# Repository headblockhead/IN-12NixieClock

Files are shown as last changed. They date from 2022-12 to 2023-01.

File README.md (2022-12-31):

**WARNING: this README has been translated into English using Google Translate for ease of understanding - it may not make perfect sense**

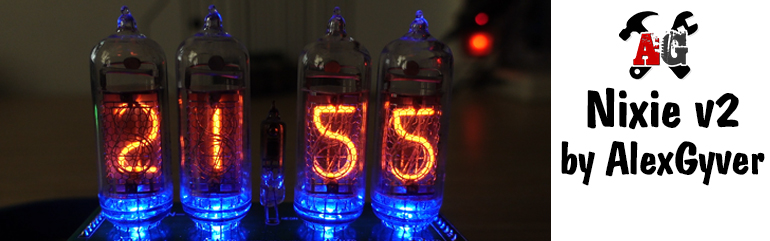
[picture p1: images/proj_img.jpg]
PROJECT_PHOTO

# Clock on gas discharge indicators and Arduino
* [Project Description](#description-of-the-project)
* [Project folders](#folders)
* [Connection diagrams](#scheme)
* [Materials and components](#materials-and-components)
* [How to download and flash](#how-to-download-and-flash)
* [FAQ](#faq)
* [Useful information](#helpful-information)
AlexGyver YouTube (https://www.youtube.com/channel/UCgtAOyEQdAyjvm9ATCi_Aig?sub_confirmation=1)

## Description of the project
Clock on Soviet gas-discharge indicators under the control of the Arduino platform, version 2.
Project page on the website: https://alexgyver.ru/nixieclock_v2/

I decided to make the simplest and most affordable clock project on gas discharge indicators and Arduino! Single-sided board, output components, no tin!

Boards:
- The dimensions of the board are less than 100x100mm, that is, ordering 10 such boards from the Chinese will cost $ 2, excluding delivery
- The board is one-sided, it can be made into a classic LUT without any problems!
- All components are output, even a beginner can solder
- The number of components is reduced to a minimum!
- At the moment, the project has boards for indicators IN-12 and IN-14, perhaps others will be made
- The system consists of two boards: the bottom (all control electronics) and the top (lamps and backlight LEDs)
- There are two options for the lower boards: normal (4 optocouplers, dot - LED) and with an additional optocoupler for a neon dot (5 optocouplers, dot - neon)
- The boards IN-14, IN-12, IN-12_changeling have the same lower part! Parts of the boards are interchangeable. The bottom board is different only for IN-14_neon  

Hardware chips:
- The heart of the board is a full size Arduino NANO, which means easy assembly and firmware
- Power supply of the entire circuit - 5 Volts
- The high voltage generator is driven by the Arduino PWM channel
- The generator voltage is adjusted by a resistor with a twist
- Time sets RTC DS3231
- 3 buttons to set time and alarm
- Alarm buzzer
- Illumination of indicator lamps
- The project is based on Andrey Zheleznyakov's board. Thank you! Link to the project: https://goo.gl/xTVQWP  

Software features:
- “Search” of numbers, preventing the indicators from oxidizing
- Alarm mode
- Smooth change in the brightness of the dot and backlight ("breathing" effect)
	+ Advanced settings for smooth breathing
- Setting the brightness of numbers, “points” and lamp illumination
	+ Two brightness modes depending on the time of day
- Different modes of switching indicators
	+ Smooth fade in/out
	+ Numeric brute force
	+ Enumeration of cathodes

## Folders
**ATTENTION! If this is your first experience with Arduino, read the [manual](#chapter-4)**
- **libraries** - project libraries. Replace existing versions (there are no external libraries in this project)
- **firmware** - firmware for Arduino
- **schemes** - component connection diagrams

## Scheme
Boards:
- IN-14 - for indicators IN-14 with LED dot https://easyeda.com/editor#id=1d7c359f88254c9d9c7ce9de914bd4c5
- IN-14_mini_neon_dot - for IN-14 with dot - indicator (+1 optocoupler and resistor) https://easyeda.com/editor#id=be6c3cd8d42a414b8a8e5b9bdd0401bf
- IN-12 - for IN-12, the numbers are upside down (when looking at the board) https://easyeda.com/editor#id=1d7c359f88254c9d9c7ce9de914bd4c5
- IN-12_turned - for IN-12, numbers are turned correctly https://easyeda.com/editor#id=aea22745380847b5beeca679820e7565  

By opening the board via the link, it can be exported to PDF, PNG or Altium (folder icon on the top left / export) for manufacturing by LUT or other methods!  
When ordering boards from the Chinese, do not forget to indicate in the comment "Please make V-cut along middle thick horizontal outline" to cut the board along the middle line  
**Gerber files are already in the archive!**
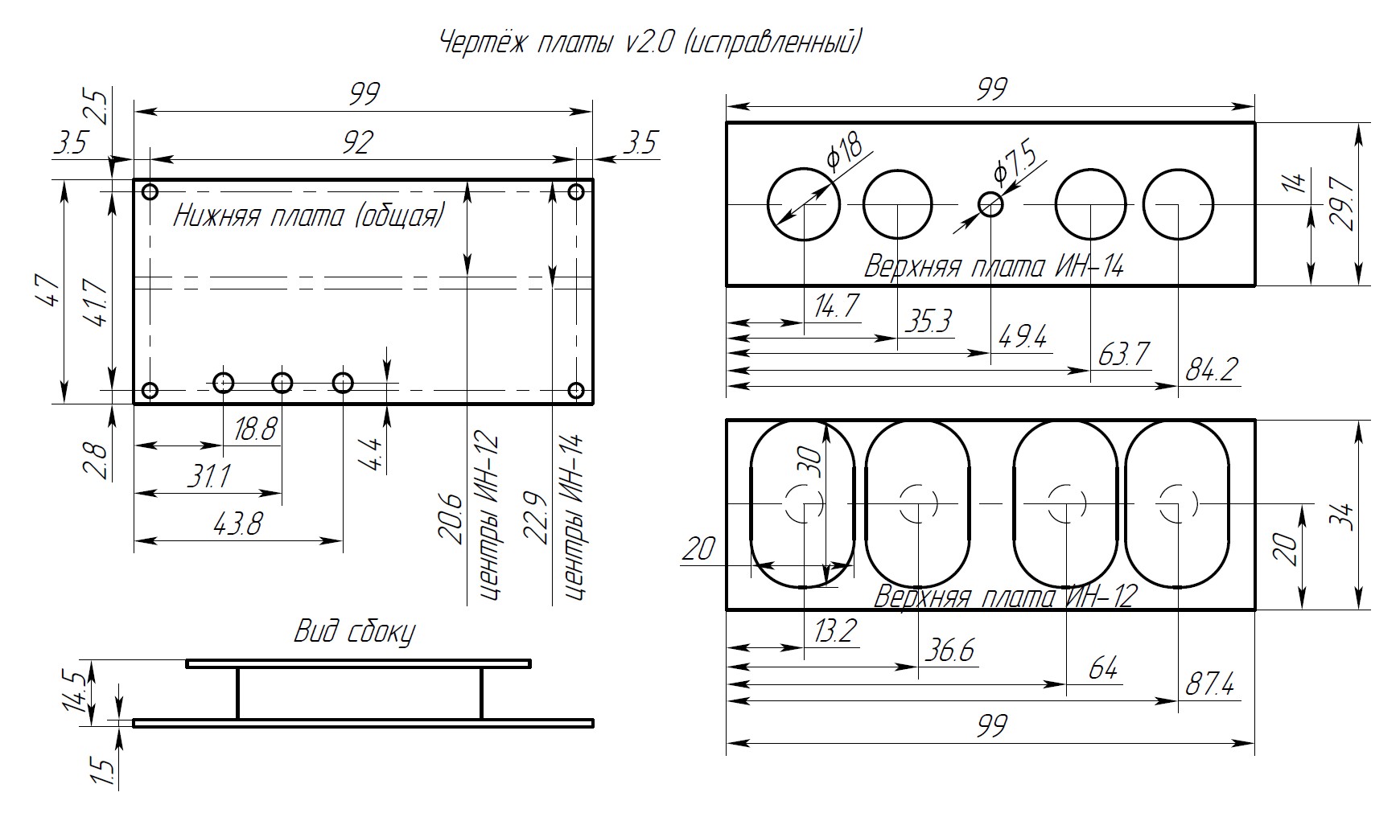
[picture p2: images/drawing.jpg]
SCHEME


## Materials and components
### Links are left to stores from which I have been buying for more than one year
- Arduino NANO Rev3.0 https://ali.ski/670JrC https://ali.ski/_7IUJ
- RTC DS3231 https://ali.ski/gOYYG0
- Squeaker https://ali.ski/8LEYlE
- Sockets for the board https://www.chipdip.ru/product/pbs-40
- Pin rail https://www.chipdip.ru/product/pls-40
- Electrolytic capacitor 4.7 uF 350V https://www.chipdip.ru/product0/33635
- Trimmer resistor 470 kOhm (can be 500 kOhm) https://www.chipdip.ru/product/3362p-1-504
- Inductance 220 uH (uH) https://www.chipdip.ru/product/ec24-221k
- Diode HER106 https://www.chipdip.ru/product/her106
- Transistor IRF840PBF https://www.chipdip.ru/product/irf840
- Optocoupler TLP627(F) DIP-4 https://www.chipdip.ru/product/tlp627
- Decoder K155ID1 https://www.chipdip.ru/product/k155id1
- Resistors 0.25 W for version IN12/IN14 with LED dot
	- 150 Ohm
	- 470 Ohm
	- 10 kOhm	
	- 100 Ohm - 3pcs	
- Resistors 0.25 W for version IN14 with neon dot
	- 200 kOhm
	- 470 Ohm
	- 10 kOhm	
	- 100 Ohm - 3pcs

## You will most likely need
* [All for soldering (soldering irons and gadgets)](http://alexgyver.ru/all-for-soldering/)
* [Inexpensive tools](http://alexgyver.ru/my_instruments/)
* [All existing Arduino modules and sensors](http://alexgyver.ru/arduino_shop/)
* [Electronic components](http://alexgyver.ru/electronics/)
* [Batteries and charging modules](http://alexgyver.ru/18650/)

## How to download and flash
* [First steps with Arduino] (http://alexgyver.ru/arduino-first/) - an ultra detailed article on getting started with Arduino, read it first!
* Download the archive with the project
> On the main page of the project (where you are reading this text) at the top right there is a green button **Clone or download**, click it, there will be **Download ZIP**
* Install libraries in  
`C:\Program Files (x86)\Arduino\libraries\` (Windows x64)  
`C:\Program Files\Arduino\libraries\` (Windows x86)
* **Connect external power supply 5 Volt**
* Connect Arduino to computer
* Run the firmware file (which has the .ino extension)
* Configure IDE (COM port, Arduino model, as in the article above)
* Customize what you need for the project
* Click download
* Enjoy  

## FAQ

### Main questions
Q: How to download from this fucking site?  
A: On the main page of the project (where you are reading this text) there is a green button **Clone or download** at the top right, click it, there will be **Download ZIP**

Q: Some .zip file was downloaded, where is it now?  
A: This is an archive. You can open it using standard Windows tools, but I think everyone has WinRAR installed on their computer, you need to right-click the archive and extract it.

Q: I'm a total newbie! What should I do with Arduino, where can I get all the programs?  
A: Read and watch the video http://alexgyver.ru/arduino-first/

Q: Loading / compilation error crashes!
A: Read here: https://alexgyver.ru/arduino-first/#step-5

Q: How much does it cost?  
A: I don't sell anything.

### Questions about this project

## Helpful information
* [My site](http://alexgyver.ru/)
* [Main YouTube channel](https://www.youtube.com/channel/UCgtAOyEQdAyjvm9ATCi_Aig?sub_confirmation=1)
* [YouTube channel about Arduino](https://www.youtube.com/channel/UC4axiS76D784-ofoTdo5zOA?sub_confirmation=1)
* [My soldering video tutorials](https://www.youtube.com/playlist?list=PLOT_HeyBraBuMIwfSYu7kCKXxQGsUKcqR)
* [My video tutorials on Arduino](http://alexgyver.ru/arduino_lessons/)

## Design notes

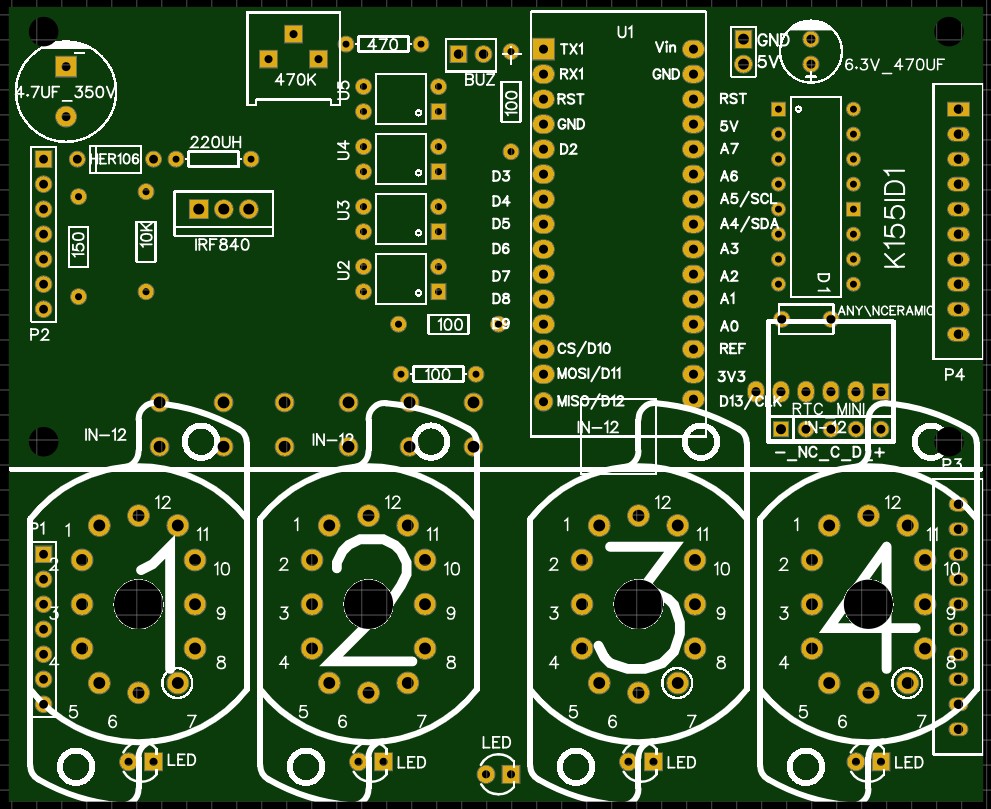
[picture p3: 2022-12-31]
images/IN-12_norm.jpg

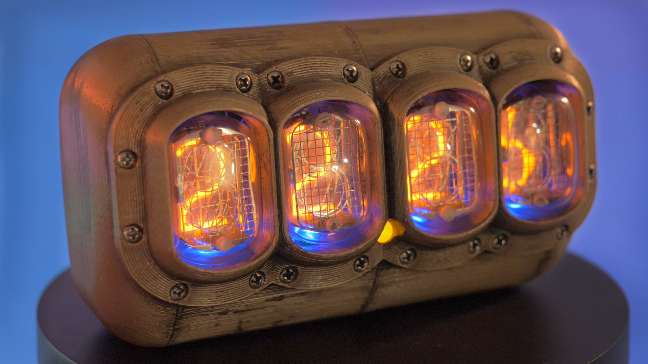
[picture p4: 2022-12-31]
images/casephoto.jpg

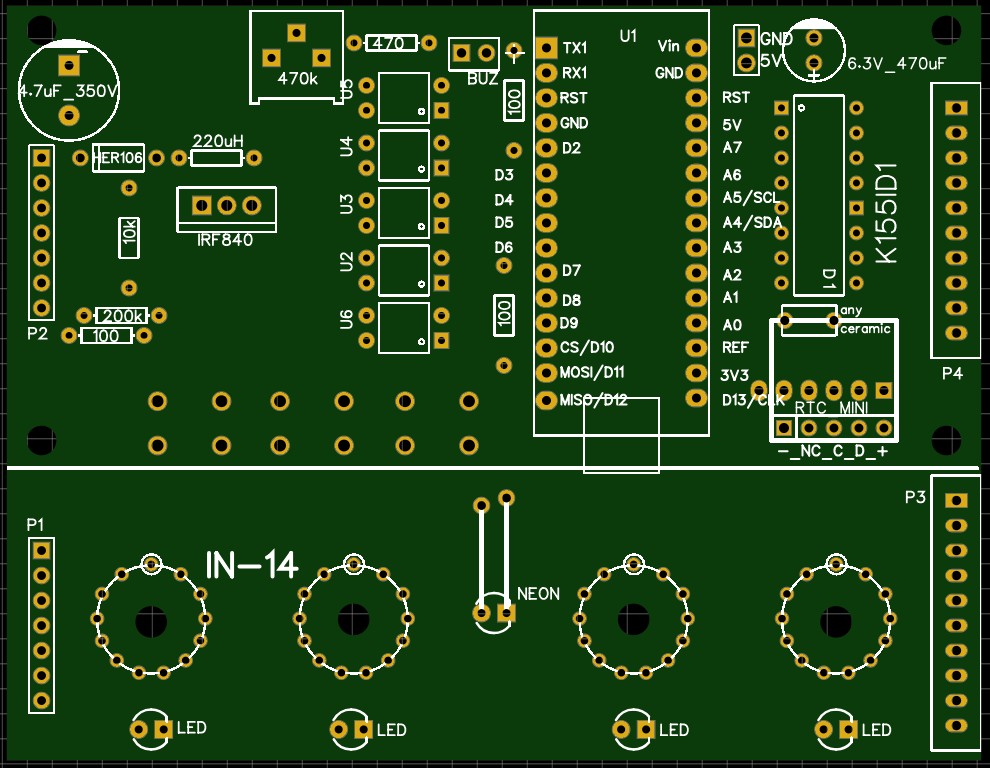
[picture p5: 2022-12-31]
images/IN-14_NEON.jpg

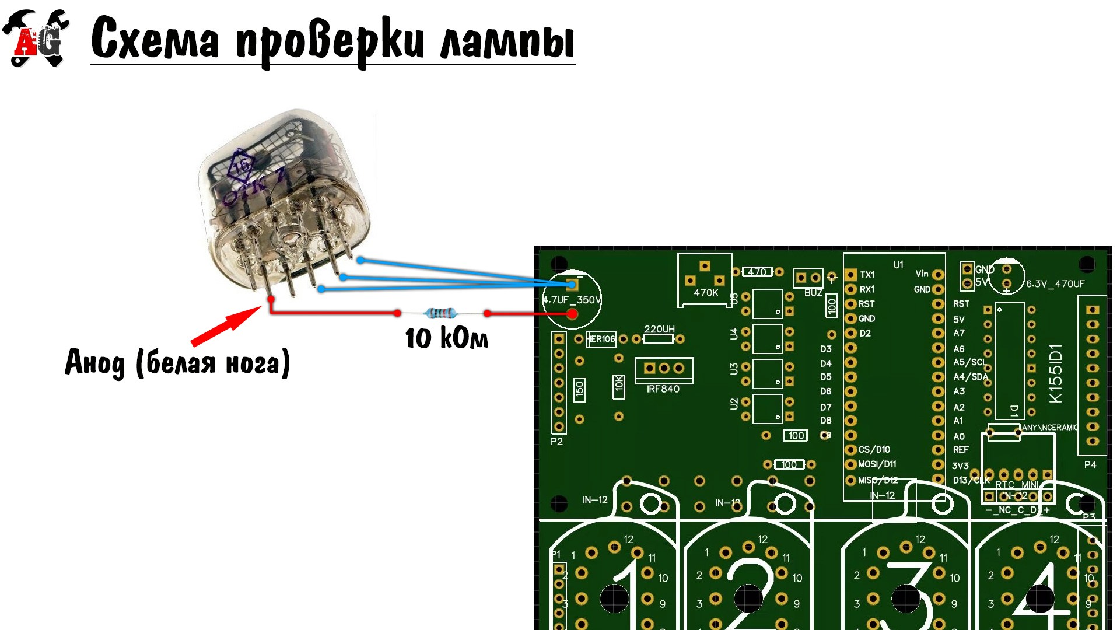
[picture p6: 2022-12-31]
images/lamp-check.jpg

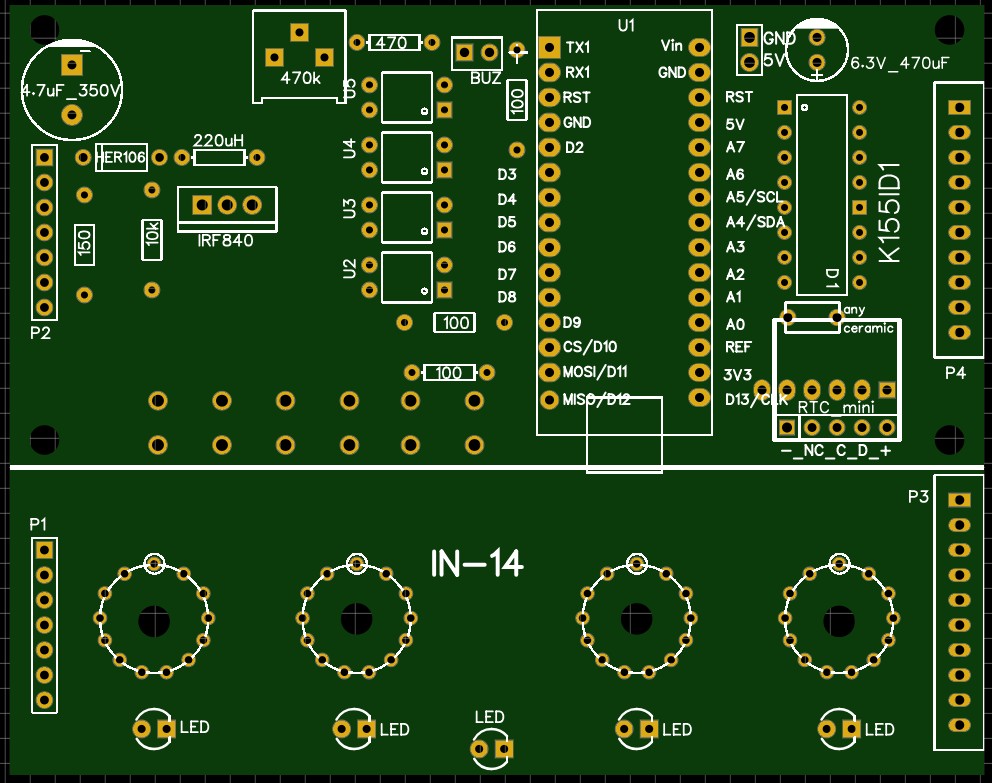
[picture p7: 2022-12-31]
images/IN-14.jpg

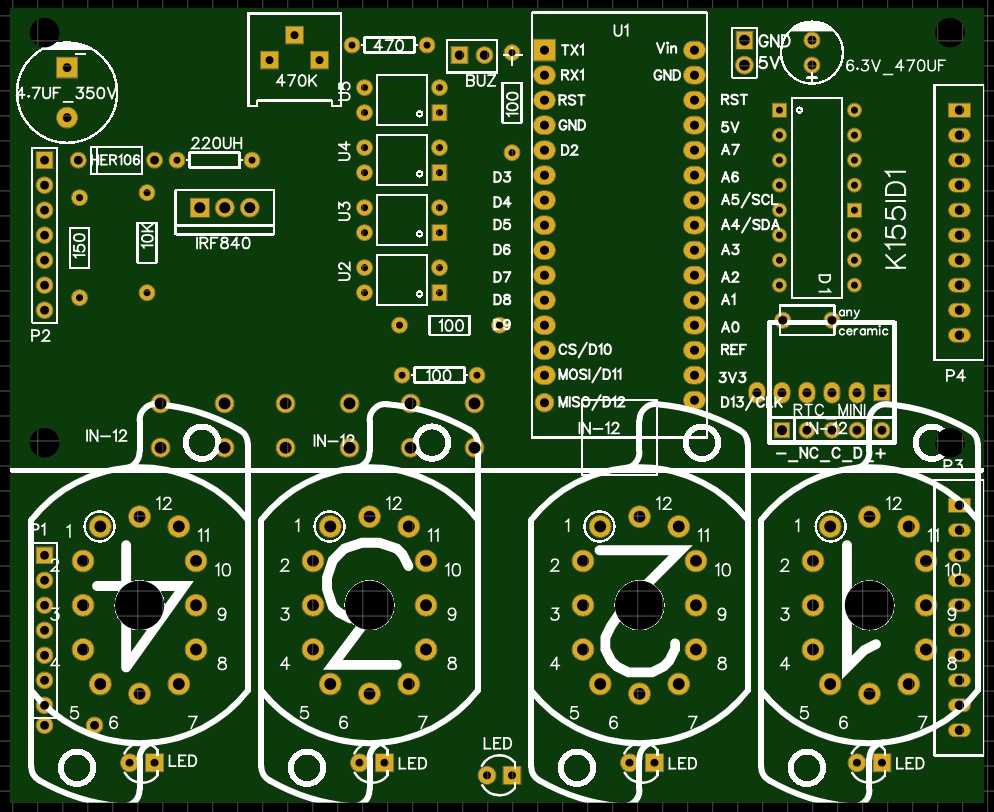
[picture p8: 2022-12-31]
images/IN-12.jpg

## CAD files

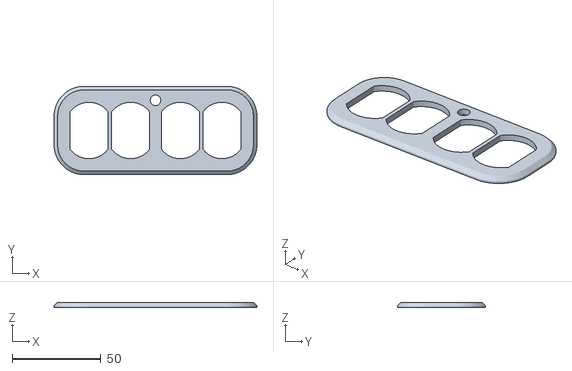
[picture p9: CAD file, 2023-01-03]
case/FrontPanel.stl
114.5 x 49.9 x 3.00

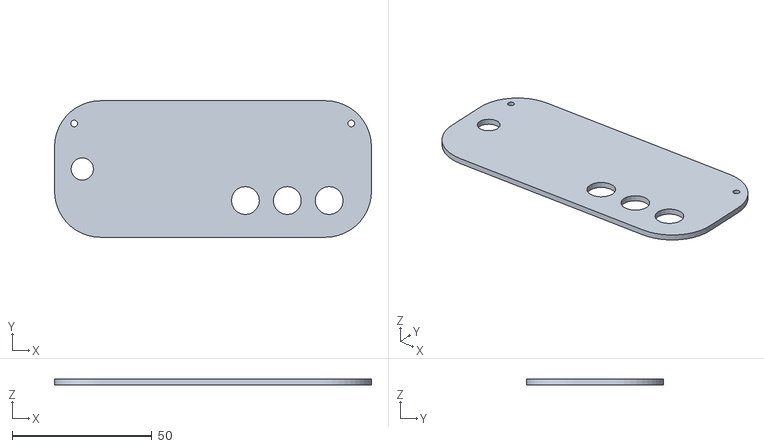
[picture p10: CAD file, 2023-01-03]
case/BackPanel.stl
113.5 x 48.9 x 2.00

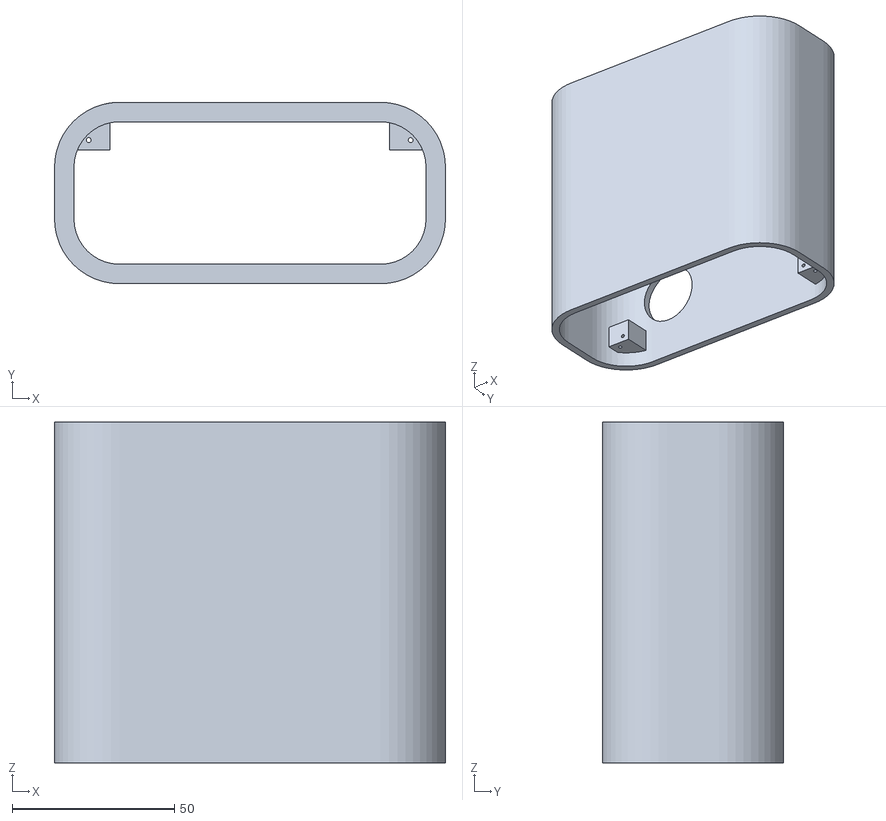
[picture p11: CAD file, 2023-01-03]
case/Chassis.stl
120.5 x 55.9 x 105.0

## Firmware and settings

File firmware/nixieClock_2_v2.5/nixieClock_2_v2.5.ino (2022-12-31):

/*
  Sketch for the project "Clock on GRI version 2"
  Project page (diagrams, descriptions): https://alexgyver.ru/nixieclock_v2/
  Sources on GitHub: https://github.com/AlexGyver/NixieClock_v2
  Like the way the code is written? Support the author! https://alexgyver.ru/support_alex/
  Author: AlexGyver Technologies, 2018
  https://AlexGyver.ru/
*/

/*
  Control:
  - Time setting:
    - Left button - selection, the rest are "greater" and "less"
    - Hold "select" - time setting
    - Click on "select" - change hour/minute setting
    - Click "more" and "less" - change the time
    - Hold "select" - return to clock mode

  - Effect control IN CLOCK MODE:
    - Holding the central button turns on and off the "glitches"
    - Click on the central button to switch the lighting modes of the lamps
      - Breath
      - Permanent glow
      - Disabled
    - Clicking on the right button toggles the number scrolling modes
      - no effect
      - Smooth fade
      - Rewind in numerical order
      - Rewind on cathodes
      - Train
      - Elastic
*/
/*
  Version 2.0 (together with Pavel Smelov):
  - Fixed jambs with backlight
  - Added switching effects "train" and "gum"
  - Optimized code

  Version 2.1:
  - Fixed a bug with the passage of time

  Version 2.2:
  - Reset seconds when setting time
  
  Version 2.3:
  - Added advanced brightness settings
  - Fixed freezes at zero values of some settings

  Version 2.4:
  - We continue to fix bugs with zero settings

  Version 2.5 ***THIS VERSION***:
  - Demonstration of the effect when selected
*/

// ************************** SETTINGS **************************
#define BOARD_TYPE 0
// clock board type:
// 0 - IN-12 turned (indicators are correct)
// 1 - IN-12 (indicators are upside down)
// 2 - IN-14 (regular and neon dot)
// 3 other indicators

#define DUTY 200        // PWM duty cycle. The voltage depends on the duty cycle! I have 175 volts at 180 and 145 volts at 120

// ======================= EFFECTS ========================
// clock flip effects
byte FLIP_EFFECT = 0;
// The selected one is active at the first start and is changed by buttons. Memorized in memory
// 0 - no effect
// 1 - fade in and out (recommended speed: 100-150)
// 2 - rewind in numerical order (recommended speed: 50-80)
// 3 - rewind in order of the cathodes in the lamp (recommended speed: 30-50)
// 4 - train (recommended speed: 50-170)
// 5 - elastic band (recommended speed: 50-150)


// ======================= BRIGHTNESS =======================
#define NIGHT_LIGHT 1       // Change brightness from time of day (1 on, 0 off)
#define NIGHT_START 23      // hour of transition to night illumination (BRIGHT_N)
#define NIGHT_END 7         // hour of transition to daylight (BRIGHT)

#define INDI_BRIGHT 23      // the brightness of the digits is daytime (1 - 24)! 24 may create burn-in!
#define INDI_BRIGHT_N 8     // night brightness (1 - 24)

#define DOT_BRIGHT 35       // dot brightness daytime (1 - 255)
#define DOT_BRIGHT_N 15     // dot brightness at night (1 - 255)

#define BACKL_BRIGHT 250    // Max. daytime lamp brightness (0 - 255)
#define BACKL_BRIGHT_N 50   // Max. lamp backlight brightness at night (0 - 255, 0 - backlight off)
#define BACKL_MIN_BRIGHT 20 // min. brightness of lamp illumination in breathing mode (0 - 255)
#define BACKL_PAUSE 400     // "darkness" interval between flashes of lamp illumination in breathing mode, ms

// ======================= Glitches =======================
#define GLITCH_MIN 30       // minimum time between glitches, seconds
#define GLITCH_MAX 120      // maximum time between glitches, seconds

// ======================  BLINK =======================
#define DOT_TIME 500        // dot flashing time, ms
#define DOT_TIMER 20        // dot brightness step, ms

#define BACKL_STEP 2        // backlight flashing step
#define BACKL_TIME 5000     // backlight period, ms

// ==================  ANTI BURN-IN ====================
#define BURN_TIME 10        // indicator bypass period in cleaning mode, ms
#define BURN_LOOPS 3        // number of cleaning cycles for each period
#define BURN_PERIOD 15      // anti-burn-in period, minutes


// *********************** FOR DEVELOPERS ***********************
byte BACKL_MODE = 0;                          // The selected one is active at startup and can be changed with buttons
byte FLIP_SPEED[] = {0, 130, 50, 40, 70, 70}; // effects speed, ms (do not change the number)
byte FLIP_EFFECT_NUM = sizeof(FLIP_SPEED);    // number of effects
boolean GLITCH_ALLOWED = 1;                   // 1 - enable, 0 - disable glitches. Button controlled

// --------- ALARM ---------
#define ALM_TIMEOUT 30      // alarm timeout
#define FREQ 900            // alarm frequency

// pins
#define PIEZO 2   // alarm
#define KEY0 3    // hours
#define KEY1 4    // hours
#define KEY2 5    // minutes
#define KEY3 6    // minutes
#define BTN1 7    // button 1
#define BTN2 8    // button 2
#define GEN 9     // generator
#define DOT 10    // point
#define BACKL 11  // backlight
#define BTN3 12   // button 3

// decoder
#define DECODER0 A0
#define DECODER1 A1
#define DECODER2 A2
#define DECODER3 A3

// lamp pinout
#if (BOARD_TYPE == 0)
const byte digitMask[] = {7, 3, 6, 4, 1, 9, 8, 0, 5, 2};   // board decoder mask IN-12-turned (normal numbers)
const byte opts[] = {KEY0, KEY1, KEY2, KEY3};              // order of indicators from left to right
const byte cathodeMask[] = {1, 6, 2, 7, 5, 0, 4, 9, 8, 3}; // cathode order IN-12

#elif (BOARD_TYPE == 1)
const byte digitMask[] = {2, 8, 1, 9, 6, 4, 3, 5, 0, 7};   // board decoder mask IN-12 (numbers upside down)
const byte opts[] = {KEY3, KEY2, KEY1, KEY0};              // order of indicators from right to left (for IN-12 turned) and IN-14
const byte cathodeMask[] = {1, 6, 2, 7, 5, 0, 4, 9, 8, 3}; // cathode order IN-12

#elif (BOARD_TYPE == 2)
const byte digitMask[] = {9, 8, 0, 5, 4, 7, 3, 6, 2, 1};   // IN-14 board decoder mask
const byte opts[] = {KEY3, KEY2, KEY1, KEY0};              // order of indicators from right to left (for IN-12 turned) and IN-14
const byte cathodeMask[] = {1, 0, 2, 9, 3, 8, 4, 7, 5, 6}; // cathode order IN-14

#elif (BOARD_TYPE == 3)
const byte digitMask[] = {0, 1, 2, 3, 4, 5, 6, 7, 8, 9};   // here enter your order of pins
const byte opts[] = {KEY0, KEY1, KEY2, KEY3};              // own order of indicators
const byte cathodeMask[] = {0, 1, 2, 3, 4, 5, 6, 7, 8, 9}; // and its order of cathodes

#endif

/*
  ард ног ном
  А0  7   4
  А1  6   2
  А2  4   8
  А3  3   1
*/

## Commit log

2022-12-31 deleted older case versions and moved images to seperate folder
    [body.step, body.stl, fusion project.f3d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]
2023-01-03 updated case 3D files
    [BackPanel.stl, Chassis.stl, FrontPanel.stl]
